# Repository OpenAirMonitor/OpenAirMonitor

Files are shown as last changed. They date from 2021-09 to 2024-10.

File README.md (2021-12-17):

# OpenAirMonitor

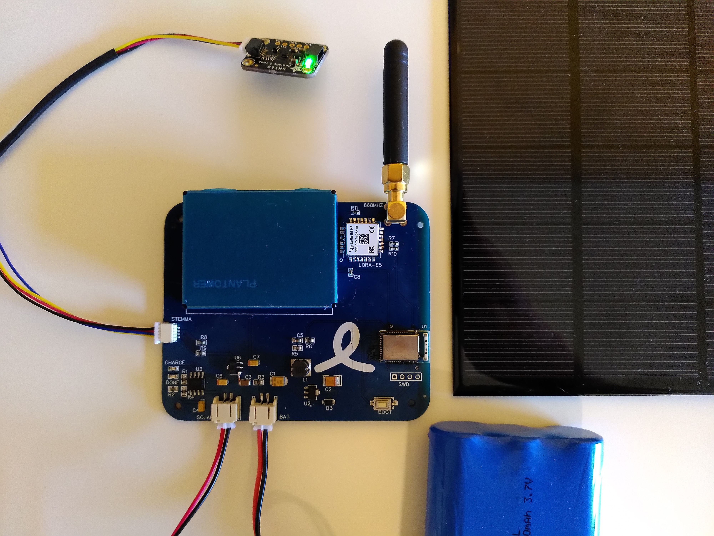
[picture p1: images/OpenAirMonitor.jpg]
OpenAirMonitor


**Work in progress**

The OpenAirMonitor is a solar-powered, outdoor air quality monitor that transmits data over LoRaWAN and Bluetooth LE. It measures particulates (PM1, PM2.5 and PM10), humidity and temperature. The monitor has a STEMMA QT connector, so can be extended with other sensors.

The monitor is programmed in JavaScript over Bluetooth LE using [Espruino](https://www.espruino.com/).

The following components can be connected to the PCB:

- PMS7003 particulate matter sensor
- 868MHz (EU/UK) SMA antenna
- 3.7V LiPo battery, e.g. [this 6600mAh battery](https://shop.pimoroni.com/products/lithium-ion-battery-pack?variant=23417820487)
- 6V solar panel
- [SHT40 temperature & humidity sensor](https://shop.pimoroni.com/products/adafruit-sensirion-sht40-temperature-humidity-sensor-stemma-qt-qwiic) using STEMMA QT connector

## Hardware

See this [OSHWLab project](https://oshwlab.com/gendor/air-quality-monitor) for schematic, PCB layout and Bill of Materials.

The LoRa-E5 module can be obtained from [Seeed Studio's webshop](https://www.seeedstudio.com/LoRa-E5-Wireless-Module-p-4745.html), or as part of their [Fusion PCB Assembly Service](https://www.seeedstudio.com/prototype-pcb-assembly.html).

## Software

Upload `main.js` to the MDBT42Q module over Bluetooth LE using Espruino.

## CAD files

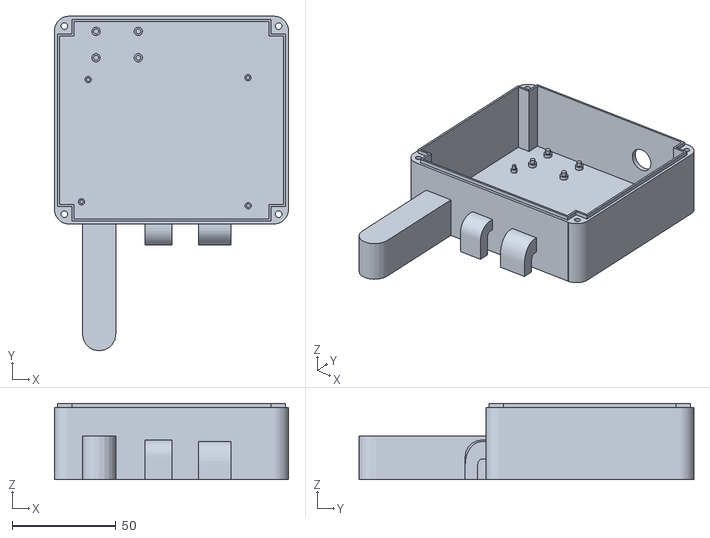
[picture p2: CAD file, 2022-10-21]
enclosure/box_only.stl
112.6 x 161.0 x 36.7

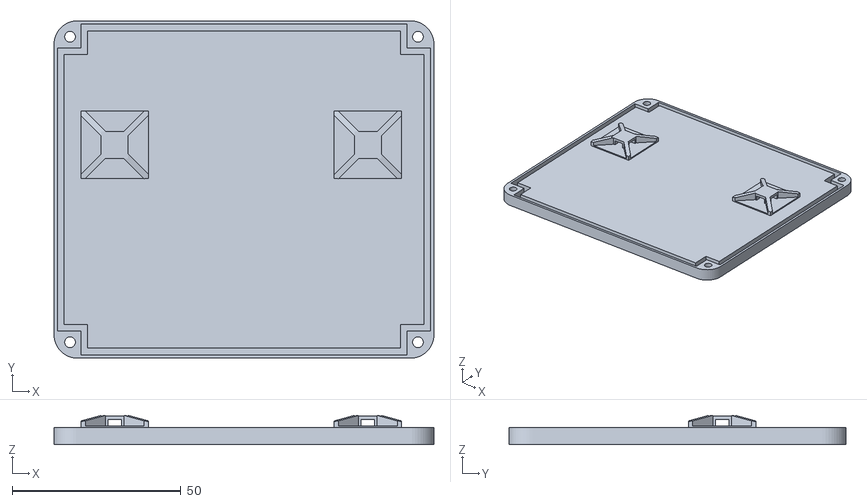
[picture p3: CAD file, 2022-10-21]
enclosure/lid.stl
112.6 x 100.0 x 8.66

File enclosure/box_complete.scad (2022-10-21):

/*
Original version licensed under [CC-BY-SA](https://creativecommons.org/licenses/by-sa/3.0/)
by [mcseven on Thingiverse](https://www.thingiverse.com/thing:1680291)
https://www.thingiverse.com/thing:1680291

Modified by [Gerrit Niezen](https://github.com/OpenAirMonitor/OpenAirMonitor/tree/main/enclosure)

Also contains bent pipe segments from:
https://github.com/fo-am/sonic-kayaks/blob/master/hardware/3dp/pm-box-home-print.scad
Sonic Kayak sensors, electronics designs and waterproofing systems Copyright (C) 2020 FoAM Kernow
CERN Open Hardware Licence Version 2 - Strongly Reciprocal

*/

lid = true;
box = true;

use <include/zip_tie_cable_holder.scad>;

/* [Box Options] */
// Dimension: Box outer X-Size [mm]
box_Size_X          = 112.6;
// Dimension: Box outer Y-Size [mm]
box_Size_Y          = 100;
// Dimension: Box Inner height [mm]
box_Inner_Height    = 33.6;
// Box bottom/top thickness
box_BottomTop_Thickness =  1.2; // [0.6:0.2:3]
// Edge corner radius 
box_Screw_Corner_Radius   =  7; // [2:1:10]
// four outer screw hole diameters
box_Screw_Diameter     =  3.2; // [2:0.2:4]
// Box wall thickness
box_Wall_Thickness     =  2.5; // [0.4:0.2:3.2]
/* [Top Barrier Options] */
// Box barrier thickness
barrier_Thickness  =  1; // [0.4:0.2:3.2]
// Box barrier height
barrier_Height     =  3.8;   // [1.0:0.2:8]
// Additional width on the lid to correct for badly calibrated printers
barrier_Tolerance  =  0.5; // [0.0:0.1:1]
/* [Mouting Screw Nose Options] */
// Number of screw noses
screwnose_Number        = 2; // [0:No noses, 2: one top/one bottom, 4: two top/two bottom]
// Diameter of the noses' screw holes
screwnose_Diameter      = 4; // [2:0.2:8]
// Height of the noses
screwnose_Height        = 5; // [2:0.2:10]
// Wall thickness
screwnose_Wall_Thickness = 2.8; // [2:0.2:5]

$fn = 40;
sideLength = 100;
faceplateLength = 120;
height = 20;
holeLength = 12;

%rotate([0, 0, 180])
translate([-1130, 774, 2])
resize([88, 0, 0], true)
import("include/PCB.stl");

// **************************
// ** Calculated globals
// **************************
boxHeight = box_Inner_Height+box_BottomTop_Thickness;

module box() {
	barrier_Thickness = box_Wall_Thickness-barrier_Thickness;
	difference() {
		union() {
			// solid round box, corners
			translate([box_Screw_Corner_Radius, box_Screw_Corner_Radius, 0]) cylinder(r=box_Screw_Corner_Radius, h=boxHeight, $fn=50); // bottom left
			translate([box_Size_X-box_Screw_Corner_Radius, box_Screw_Corner_Radius, 0]) cylinder(r=box_Screw_Corner_Radius, h=boxHeight, $fn=50); // bottom right
			translate([box_Screw_Corner_Radius, box_Size_Y-box_Screw_Corner_Radius, 0]) cylinder(r=box_Screw_Corner_Radius, h=boxHeight, $fn=50); // top left
			translate([box_Size_X-box_Screw_Corner_Radius, box_Size_Y-box_Screw_Corner_Radius, 0]) cylinder(r=box_Screw_Corner_Radius, h=boxHeight, $fn=50); // bottom right
			// solid round box, inner filling
			translate([0, box_Screw_Corner_Radius, 0]) cube([box_Size_X, box_Size_Y-2*box_Screw_Corner_Radius, boxHeight]);
			translate([box_Screw_Corner_Radius, 0, 0]) cube([box_Size_X-2*box_Screw_Corner_Radius, box_Size_Y, boxHeight]);
			// solid round box, top border
			translate([barrier_Thickness, box_Screw_Corner_Radius+barrier_Thickness, 0]) cube([box_Size_X-2*barrier_Thickness, box_Size_Y-2*box_Screw_Corner_Radius-2*barrier_Thickness, boxHeight+(barrier_Height/2)]);
			translate([box_Screw_Corner_Radius+barrier_Thickness, barrier_Thickness, 0]) cube([box_Size_X-2*box_Screw_Corner_Radius-2*barrier_Thickness, box_Size_Y-2*barrier_Thickness, boxHeight+(barrier_Height/2)]);
      
      // antenna cover
      translate([21.5, -53, 0]) cylinder(r=8, h=21, $fn=20);   
      rotate([90, 0, 0]) translate([13.5, 0, 0]) cube([16, 21, 53]);
		}
		// inner cut-out
		translate([box_Wall_Thickness, box_Screw_Corner_Radius+box_Wall_Thickness, box_BottomTop_Thickness]) cube([box_Size_X-2*box_Wall_Thickness, box_Size_Y-2*box_Screw_Corner_Radius-2*box_Wall_Thickness, boxHeight+barrier_Height]);
		translate([box_Screw_Corner_Radius+box_Wall_Thickness, box_Wall_Thickness, box_BottomTop_Thickness]) cube([box_Size_X-2*box_Screw_Corner_Radius-2*box_Wall_Thickness, box_Size_Y-2*box_Wall_Thickness, boxHeight+barrier_Height]);
		// Screw holes
		translate([(box_Screw_Corner_Radius+box_Wall_Thickness)/2,(box_Screw_Corner_Radius+box_Wall_Thickness)/2,0]) cylinder(r=box_Screw_Diameter/2, h=boxHeight+1, $fn=20);
		translate([(box_Screw_Corner_Radius+box_Wall_Thickness)/2,box_Size_Y-(box_Screw_Corner_Radius+box_Wall_Thickness)/2,0]) cylinder(r=box_Screw_Diameter/2, h=boxHeight+1, $fn=20);
		translate([box_Size_X-(box_Screw_Corner_Radius+box_Wall_Thickness)/2,(box_Screw_Corner_Radius+box_Wall_Thickness)/2,0]) cylinder(r=box_Screw_Diameter/2, h=boxHeight+1, $fn=20);
		translate([box_Size_X-(box_Screw_Corner_Radius+box_Wall_Thickness)/2,box_Size_Y-(box_Screw_Corner_Radius+box_Wall_Thickness)/2,0]) cylinder(r=box_Screw_Diameter/2, h=boxHeight+1, $fn=20);
		// **************************
		// ** YOUR OWN CUTOUTS HERE!
		// **************************
        
        // faceplate
        rotate([90, 0, 0]) {

            translate([7, 0, 0]) {
                
                //antenna hole
                translate([8.5, 1.2, -4])
                   cube([12, 18, 59]);

                
                // PMS7003 holes
                translate([38, 14.5, -(holeLength/2)]) {
                    cube([10, 3, holeLength]);
                    
                    translate([26, -3, 0])
                        cube([12.5, 6, holeLength]);
                }
                
                // hole for solar panel
                translate([70, 17, -(holeLength/2)-sideLength])
                    cylinder(holeLength, d = 12);
                
                // inset for PMS7003 sensor
                // translate([34, 1, -3])
                //     cube([55, 20, 2]);
                
            }
        }

		// **************************
		// ** / CUTOUTS
		// **************************
	}
    /*
	// Lower nose(s)
	if (screwnose_Number==2) translate([box_Size_X/2, 0.001, 0]) mirror([0,1,0]) screwNose(screwnose_Diameter, screwnose_Height);
	if (screwnose_Number==4) {
		translate([box_Size_X*0.25, 0.001, 0]) mirror([0,1,0]) screwNose(screwnose_Diameter, screwnose_Height);
		translate([box_Size_X*0.75, 0.001, 0]) mirror([0,1,0]) screwNose(screwnose_Diameter, screwnose_Height);
	}
	// Upper nose(s)
	if (screwnose_Number==2) translate([box_Size_X/2, box_Size_Y-0.001, 0]) screwNose(screwnose_Diameter, screwnose_Height);
	if (screwnose_Number==4) {
		translate([box_Size_X*0.25, box_Size_Y-0.001, 0]) screwNose(screwnose_Diameter, screwnose_Height);
		translate([box_Size_X*0.75, box_Size_Y-0.001, 0]) screwNose(screwnose_Diameter, screwnose_Height);
	}
    */
}

module mountPCB() {
    translate([1, 1, 0]) {
        translate([12, 9.7, 0]) {
            cylinder(5, d = 1.7);
            cylinder(3, d = 3);
        }

        translate([92.2, 7.8, 0]) {
            cylinder(5, d = 1.7);
            cylinder(3, d = 3);
        }

        translate([92.1, 69.4, 0]) {
            cylinder(5, d = 1.7);
            cylinder(3, d = 3);
        }

        translate([15.2, 68.5, 0]) {
            cylinder(5, d = 1.7);
            cylinder(3, d = 3);
        }
    }
}

module mountSensor() {
    holeDiameter = 2.4;
    holeX = 20.32;
    holeY = 12.7;
    
    translate([20, 80, 0]) {

        cylinder(5, d = holeDiameter);
        cylinder(3, d = 4);


        translate([holeX, 0, 0]) {
            cylinder(5, d = holeDiameter);
            cylinder(3, d = 4);
        }

        translate([0, holeY, 0]) {
            cylinder(5, d = holeDiameter);
            cylinder(3, d = 4);
        }

        translate([holeX, holeY, 0]) {
            cylinder(5, d = holeDiameter);
            cylinder(3, d = 4);
        }
    }
}

module nutHole() {
    cylinder(r=box_Screw_Diameter/2, h=boxHeight, $fn=20);
    cylinder(d=6.2, h=2.6, $fn=6);
}
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

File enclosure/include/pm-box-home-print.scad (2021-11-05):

/*
Downloaded from:
https://github.com/fo-am/sonic-kayaks/blob/master/hardware/3dp/pm-box-home-print.scad

Sonic Kayak sensors, electronics designs and waterproofing systems Copyright (C) 2020 FoAM Kernow

CERN Open Hardware Licence Version 2 - Strongly Reciprocal

*/

$fs=0.5; 
$fa=0.5; 

module sensor() {
    color("blue") 
    cube([47.7,36.7,11.7]);

    // plug
    color("black")
    translate([1.85,36.7-10-2.85,12])
    square([6,10]);

    // air out
    color("black")
    translate([4.45,37,11.7-2-8.75])
    rotate([90,0,0])
    square([9.8,2]);

    // air in
    color("black")
    translate([0,37,11.7-4.4-6.45])
    translate([47.7-11-4.45,0,0]) // ???
    rotate([90,0,0])
    square([11,4.4]);
}

nipple_width=13.0;
nipple_hole_width=11.0;
nipple_height=18.0;
nipple_hole_height=4.0;

module bent_pipe() {
    rotate([0,90,90]) {
        rotate_extrude(angle=90) {
            translate([5,0,0])
            difference() {
                square([6,nipple_width],true);
                square([4,nipple_hole_width],true);
            }            
        }
        translate([5,-1.5,0])
        difference() {
            cube([6,3,nipple_width],true);
            cube([4,3.1,nipple_hole_width],true);
        }
    }
}

module nipple() {
    bent_pipe();
}



module nipples() {
    // in nipple
    translate([69.2,40+2,0])
    rotate([90,90,0])
    nipple();

    // out nipple
    translate([41,40+2,0])
    rotate([90,90,0])
    nipple();
}


//translate([31.5,1.5,4.5]) sensor();

// internal space
//translate([0,0,0])
//color([1,1,1,0.5])
//cube([80,40,20]);

// 6-10mm internal pipe diameter


translate([0,0,3])
difference() {
    union() {
        // bottom wall
        translate([-3,-3,-3]) cube([86,46,3]);
        // back wall
        translate([0,-3,0]) cube([80,3,22]);
        // back wall
        translate([0,40,0]) cube([80,3,22]);
        // end wall
        translate([-3,-3,0]) cube([3,46,22]);
        // end wall
        translate([80,-3,0]) cube([3,46,22]);

        nipples();
        // bottom spacer
        translate([30,-3,-0.5]) cube([50,46,2]);
        // air separators
        translate([30,38.5,0])
        union() {
            cube([2,2,15]);
            translate([0,0,13])
            cube([50.5,2,2]);
            translate([20,0,0])
            cube([10,2,15]);
        }
    }
        
    translate([33,42.5,5])
    rotate([-90,180,0])
    linear_extrude(height=3) {
        union() {
            scale([0.3,0.3,1]) {
//                text("Sonic Kayaks");
                text("Sonic Bikes");
                translate([0,-13,0])
                text("Air pollution sensor");
            }
//            translate([0,5,0])
//            scale([0.75,0.75,1])
//            import("foam-logo-seg.dxf");
            scale([0.5,0.5,0.5])
            translate([0,-252,0])
            import("bri-logo.dxf");
        }
    }
    
    // cut holes through box and nipples 
    union() {
        translate([69.2,40.01,4])
        rotate([90,0,0])
        union () {
            cube([nipple_hole_width,4,10], true);
            translate([41-69.2,0,0])
            cube([nipple_hole_width,4,10], true);
        }
        translate([-5,30,15])
        rotate([0,90,0])
        cylinder(d=3.5,h=10);
    }
}


// lid
translate([-3,-5,3]) 
rotate([180,0,0])
union() {
    cube([86,46,3]);
    translate([3.5,3.5,-2])
    cube([79,39,2]);
}

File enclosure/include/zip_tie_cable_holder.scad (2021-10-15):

/*

Zip Tie Anchor by
[PeterEllens](https://www.thingiverse.com/thing:24187)
is licensed under a [CC-BY license](https://creativecommons.org/licenses/by/4.0/)

Modified by [Gerrit Niezen](https://github.com/OpenAirMonitor/OpenAirMonitor/tree/main/enclosure)

*/

module zip_tie_anchor() {
    base_width = 20;
    base_height = 1;
    gap_width = 4;
    gap_height =2;
    top_width = 8;
    top_height = 2.3;
    cross_width = 1.8;

    diaginal_width = sqrt(base_width*base_width+base_width*base_width);

    difference () {
    union() {
    cube(size=[base_width,base_width,base_height],center=true);
    translate(v=[0,0,base_height+(gap_height-base_height)/2]) cube(size=[top_width,top_width,top_height+gap_height],center=true);

    rotate(a=[0,11,45]) translate(v=[diaginal_width/4,0,base_height+gap_height]) cube(size=[diaginal_width/2,cross_width,gap_height+1],center=true);

    rotate(a=[0,11,90+45]) translate(v=[diaginal_width/4,0,base_height+gap_height]) cube(size=[diaginal_width/2,cross_width,gap_height+1],center=true);

    rotate(a=[0,11,180+45]) translate(v=[diaginal_width/4,0,base_height+gap_height]) cube(size=[diaginal_width/2,cross_width,gap_height+1],center=true);

    rotate(a=[0,11,270+45]) translate(v=[diaginal_width/4,0,base_height+gap_height]) cube(size=[diaginal_width/2,cross_width,gap_height+1],center=true);


    }
    translate(v=[0,0,base_height+(gap_height-base_height)/2]) cube(size=[gap_width,top_width+1,gap_height],center=true);
    translate(v=[0,0,base_height+(gap_height-base_height)/2]) cube(size=[top_width+1,gap_width,gap_height],center=true);

    translate(v=[0,0,base_height+(gap_height+base_height)]) cube(size=[top_width,top_width,top_height-gap_height+0.6],center=true);

    translate(v=[0,0,-base_height-(base_height)/2]) cube(size=[base_width+2,base_width+2,base_height*2],center=true);

    translate(v=[0,base_width,0]) cube(size=[base_width+5,base_width,base_height+gap_height+1],center=true);

    translate(v=[0,-base_width,0]) cube(size=[base_width+5,base_width,base_height+gap_height+1],center=true);

    translate(v=[base_width,0,0]) cube(size=[base_width,base_width+5,base_height+gap_height+1],center=true);

    translate(v=[-base_width,0,0]) cube(size=[base_width,base_width+5,base_height+gap_height+1],center=true);

    }
}

zip_tie_anchor();

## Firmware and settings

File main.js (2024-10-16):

const PMS = require('PMS7003');

const lora = {
  pins: {
    tx: D8,
    rx: D6
  },
  resetPin: D3,
};

let pmsData = null;
var pms = null;
let shtData = null;
let batteryVoltage = null;
let batteryPercentage = null;
let batteryChargeRate = null;
let joined = false;

const SCL_SDA = {
  "scl": D14,
  "sda": D13
};
const ENABLE_PM = D12;
const PM_DATA = D5;
const ENABLE_5V = D19;
const PM_INTERVAL = 3600000; // 60 minutes
const READ_TIME = 30000;
const RETRY_JOIN_DELAY = 20000;
const HAS_FUEL_GAUGE = false; // can use MAX1704X fuel gauge
const USE_SHT31 = false; // can use SHT31 instead of SHT40

const onPms = (d) => {
  // TODO: consider averaging the values
  if (d.checksumOk) {
    console.log('PM 2.5 data: ', d.dAtm.pm2_5);
    pmsData = d;
  } else {
    console.log('PMS checksum error!');
  }
  sht.read(function(d) {
    console.log('Temperature:', d.temp);
    console.log('Humidity:', d.humidity);
    shtData = d;
  });

  if (HAS_FUEL_GAUGE) {
    batteryPercentage = fuelGauge.readPercent();
    console.log(`Battery percent: ${batteryPercentage} %`);

    batteryVoltage = fuelGauge.readVoltage();
    console.log(`Battery voltage: ${batteryVoltage} V`);

    batteryChargeRate = fuelGauge.readChargeRate();
    console.log(`Battery charge rate: ${batteryChargeRate} %/hr`);

    pinVoltage = (analogRead(D31) * 3.3) * (100 + 30) / 100;
    console.log('Voltage read from pin:', pinVoltage);
  } else {
    batteryVoltage = (analogRead(D31) * 3.3) * (100 + 30) / 100;
    console.log('Voltage read from pin:', batteryVoltage);
  }
};

const arrayBufferToHex = (arrayBuffer) => {
  return (new Uint8Array(arrayBuffer)).slice().map(x => (256 + x).toString(16).substr(-2)).join("");
};

const loraSetup = (init = false) => {
  let buf = '';
  Serial1.setup(9600, lora.pins);
  digitalWrite(lora.resetPin, 1); // keep LoRa reset pin high
  if (init) {
    lora.on('MSGHEX', (result) => {
      if (result.type === 'Done') {
        lora.emit('done');
      }
    });
    lora.on('JOIN', (result) => {
      if (result.type === 'Join failed') {
        console.log('Could not join the network');
        lora.emit('retry');
      }
      if (result.type === 'Network joined') {
        console.log('Successfully joined the network');
        joined = true;
        lora.emit('ready');
      }
    });
    lora.on('MODE', (result) => {
      if (result.type === 'LWOTAA') {
        console.log('Set mode to OTAA');
        Serial1.println('AT+JOIN');
      } else {
        console.log('Could not configure channels');
      }
    });
    lora.on('CH', (result) => {
      if (result.type === 'NUM' && result.value === '0-2') {
        console.log('Configured channels');
        Serial1.println('AT+MODE=LWOTAA');
      } else {
        console.log('Could not configure channels');
      }
    });
    lora.on('DR', (result) => {
      if (result.type === 'EU868') {
        console.log('Data rate set to 868MHz');
        Serial1.println('AT+CH=NUM,0-2');
      } else {
        console.log('Could not set data rate');
      }
    });
    Serial1.println('AT+DR=EU868');
  }
  // this should be after the other lora event listeners
  Serial1.on('data', (data) => {
    buf += data;
    var idx = buf.indexOf("\r");
    while (idx >= 0) {
      const line = buf.substr(0, idx);
      buf = buf.substr(idx + 1);
      // print(line);
      const res = /\+(\w+):\s+([\w\s]+),*\s*(.*)/.exec(line);
      if (res) {
        const result = {
          cmd: res[1],
          type: res[2],
          value: res[3],
        };
        lora.emit(result.cmd, result);
      }
      idx = buf.indexOf("\r");
    }
  });
};

const Ranges = {
  DIGITAL_INPUT: [0, 255],
  DIGITAL_OUTPUT: [0, 255],
  ANALOG_INPUT: [-327.68, 327.67],
  ANALOG_OUTPUT: [-327.68, 327.67],
  LUMINOSITY: [0, 65535],
  PRESENCE: [0, 1],
  TEMPERATURE: [-3276.8, 3276.7],
  RELATIVE_HUMIDITY: [0, 100],
  ACCELEROMETER: [-32.768, 32.767],
  MAGNETOMETER: [-32.768, 32.767],
  BAROMETRIC_PRESSURE: [0, 6553.5],
  GYROMETER: [-327.68, 327.67],
  GPS_LATITUDE: [-90.0, 90.0],
  GPS_LONGITUDE: [-180.0, 180.0],
  GPS_ALTITUDE: [-3276.8, 3276.7],
};

const Scales = {
  DIGITAL_INPUT: 1,
  DIGITAL_OUTPUT: 1,
  ANALOG_INPUT: 100,
  ANALOG_OUTPUT: 100,
  LUMINOSITY: 1,
  PRESENCE: 1,
  TEMPERATURE: 10,
  RELATIVE_HUMIDITY: 2,
  ACCELEROMETER: 1000,
  MAGNETOMETER: 1000,
  BAROMETRIC_PRESSURE: 10,
  GYROMETER: 100,
  GPS_LATITUDE: 10000,
  GPS_LONGITUDE: 10000,
  GPS_ALTITUDE: 100,
};

const Sizes = {
  DIGITAL_INPUT: 1,
  DIGITAL_OUTPUT: 1,
  ANALOG_INPUT: 2,
  ANALOG_OUTPUT: 2,
  LUMINOSITY: 2,
  PRESENCE: 1,
  TEMPERATURE: 2,
  RELATIVE_HUMIDITY: 1,
  ACCELEROMETER: 6,
  MAGNETOMETER: 6,
  BAROMETRIC_PRESSURE: 2,
  GYROMETER: 6,
  GPS: 9,
  CHANNEL_TYPE: 2,
  UINT8: 1,
  UINT16: 2,
  INT16: 2,
  THREE_AXIS: 6,
};

const Types = {
  DIGITAL_INPUT: 0,
  DIGITAL_OUTPUT: 1,
  ANALOG_INPUT: 2,
  ANALOG_OUTPUT: 3,
  LUMINOSITY: 101,
  PRESENCE: 102,
  TEMPERATURE: 103,
  RELATIVE_HUMIDITY: 104,
  ACCELEROMETER: 113,
  MAGNETOMETER: 114,
  BAROMETRIC_PRESSURE: 115,
  GYROMETER: 134,
  GPS: 136,
};

const rangeCheck = (min, max, value) => {
  if (value < min || value > max) {
    throw new RangeError(`The argument must be between ${min} and ${max}.`);
  }
};

const encodeChannelType = (channel, type) => {
  const buffer = new ArrayBuffer(Sizes.CHANNEL_TYPE);
  const dataView = new DataView(buffer);
  let offset = 0;
  [channel, type].forEach((value) => {
    dataView.setInt8(offset, value);
    offset += 1;
  });
  return buffer;
};

const encodeInt16 = function encodeInt16(value, scale) {
  if (scale == null) {
    scale = 1;
  }
  const buffer = new ArrayBuffer(Sizes.INT16);
  const dataView = new DataView(buffer);
  dataView.setInt16(0, (value * scale) | 0);
  return buffer;
};

const encodeUInt8 = function encodeUInt8(value, scale) {
  if (scale == null) {
    scale = 1;
  }
  const buffer = new ArrayBuffer(Sizes.UINT8);
  const dataView = new DataView(buffer);
  dataView.setUint8(0, (value * scale) | 0);
  return buffer;
};

var concatBuffer = (buffer1, buffer2) => {
  var tmp = new Uint8Array(buffer1.byteLength + buffer2.byteLength);
  tmp.set(new Uint8Array(buffer1), 0);
  tmp.set(new Uint8Array(buffer2), buffer1.byteLength);
  return tmp.buffer;
};

const encodeAnalogInput = (channel, value) => {
  const min = Ranges.ANALOG_INPUT[0];
  const max = Ranges.ANALOG_INPUT[1];
  rangeCheck(min, max, value);
  const chanb = encodeChannelType(channel, Types.ANALOG_INPUT);
  const snsb = encodeInt16(value, Scales.ANALOG_INPUT);
  return concatBuffer(chanb, snsb);
};

const encodeTemperature = (channel, degc) => {
  const min = Ranges.TEMPERATURE[0];
  const max = Ranges.TEMPERATURE[1];
  rangeCheck(min, max, degc);
  const chanb = encodeChannelType(channel, Types.TEMPERATURE);
  const snsb = encodeInt16(degc, Scales.TEMPERATURE);
  return concatBuffer(chanb, snsb);
};

const encodeHumidity = (channel, percent) => {
  const min = Ranges.RELATIVE_HUMIDITY[0];
  const max = Ranges.RELATIVE_HUMIDITY[1];
  rangeCheck(min, max, percent);
  const chanb = encodeChannelType(channel, Types.RELATIVE_HUMIDITY);
  const snsb = encodeUInt8(percent, Scales.RELATIVE_HUMIDITY);
  return concatBuffer(chanb, snsb);
};

function MAX1704X(_i2c) {
  this.i2c = _i2c;
  this.reset();
}

MAX1704X.prototype.reset = function() {
  try {
    this.i2c.writeTo(0x36, [0xFE, 0x54, 0x00]);
  } catch (err) {
    if (err.message.includes('33282')) {
      // we got a NACK, which is what we want
      return;
    } else {
      throw new Error('Something went wrong during reset()');
    }
  }
};

MAX1704X.prototype.readRegister = function(register) {
  this.i2c.writeTo({
    address: 0x36,
    stop: false
  }, [register]);
  return new DataView(this.i2c.readFrom(0x36, 3).buffer);
};


MAX1704X.prototype.readICVersion = function() {
  return this.readRegister(0x08).getUint16().toString(16);
};

MAX1704X.prototype.readPercent = function() {
  return this.readRegister(0x04).getUint16() / 256.0;
};

MAX1704X.prototype.readVoltage = function(callback) {
  return this.readRegister(0x02).getUint16() * 78.125 / 1000000;
};

MAX1704X.prototype.readChargeRate = function(callback) {
  return this.readRegister(0x16).getInt16() * 0.208;
};

var connect2 = function(_i2c) {
  return new MAX1704X(_i2c);
};

lora.on('ready', () => {
  console.log('Finished setup, putting LoRa modem to sleep');
  Serial1.println('AT+LOWPOWER');
  lora.on('data', (pmsData, shtData, batteryVoltage) => {
    console.log('Disconnecting PM..');
    Serial1.unsetup();
    loraSetup();
    if (pmsData) {
      const pm10 = encodeAnalogInput(1, pmsData.dAtm.pm10);
      const pm2_5 = encodeAnalogInput(2, pmsData.dAtm.pm2_5);
      const temp = encodeTemperature(3, shtData.temp);
      const humidity = encodeHumidity(4, Math.round(shtData.humidity));
      const battery = encodeAnalogInput(5, batteryVoltage);
      const chargeRate = encodeAnalogInput(6, batteryChargeRate);
      // works with https://revspace.nl/Sensor-data-bridge
      const toSend = arrayBufferToHex(pm10) +
        arrayBufferToHex(pm2_5) +
        arrayBufferToHex(temp) +
        arrayBufferToHex(humidity);
      // The following can't be uploaded to sensor.community
      // arrayBufferToHex(battery) +
      // arrayBufferToHex(chargeRate);
      pmsData = null;
      Serial1.println('A'); // wakeup LoRa modem
      setTimeout(() => {
        Serial1.println(`AT+MSGHEX="${toSend}"`);
        console.log(`Sending ${toSend}`);
      }, 5);
    } else {
      console.log('No PM data available.');
    }
  });
});

lora.on('done', () => {
  console.log('Sent message, putting LoRa modem to sleep');
  Serial1.println('AT+LOWPOWER');
});

lora.on('retry', () => {
  console.log(`Waiting ${RETRY_JOIN_DELAY/1000} seconds before trying to join network again..`);
  setTimeout(() => {
    console.log('Attempting to join..');
    Serial1.println('AT+JOIN');
  }, RETRY_JOIN_DELAY);
});

function SHT31(_i2c) {
  this.i2c = _i2c;
}

// read with callback({humidity,temp})
SHT31.prototype.read = function(callback) {
  // high repeatability with clock stretching disabled
  this.i2c.writeTo(0x44, [0x24, 0x00]);
  var sht = this;
  setTimeout(function() {
    var d = new DataView(sht.i2c.readFrom(0x44, 6).buffer);
    callback({
      temp: d.getUint16(0) * 175 / 65536 - 45,
      humidity: d.getUint16(3) * 125 / 65536 - 6
    });
  }, 20);
};

var connect3 = function(_i2c) {
  return new SHT31(_i2c);
};

I2C1.setup(SCL_SDA);

var sht = null;
if (USE_SHT31) {
  sht = connect3(I2C1);
} else {
  sht = require('SHT4x').connect(I2C1);
}

var fuelGauge = null;
if (HAS_FUEL_GAUGE) {
  fuelGauge = connect2(I2C1);
}

digitalWrite(ENABLE_PM, 0);
digitalWrite(ENABLE_5V, 0);
Bluetooth.setConsole(true);

setTimeout(() => {
  loraSetup(true);
}, 1000); // Give LoRa-E5 time to start up

const pmInterval = setInterval(() => {
  if (joined) {
    console.log('Turning on PM..');
    Serial1.unsetup();
    Serial1.removeAllListeners('data');
    digitalWrite(ENABLE_5V, 1);
    pms = PMS.connect(Serial1, PM_DATA, ENABLE_PM, onPms);
    pms.wakeup();
    const readTime = setTimeout(() => {
      console.log('Turning off PM..');
      pms.sleep();
      digitalWrite(ENABLE_5V, 0);
      setTimeout(() => {
        // wait for PM sensor to sleep before sending data
        lora.emit('data', pmsData, shtData, batteryVoltage);
      }, 1000);
    }, READ_TIME);
  }
}, PM_INTERVAL);

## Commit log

2021-09-14 started on enclosure
    [PCB.dxf, main.scad, test.stl]
2021-09-17 faceplate works; working on full enclosure
    [main.scad, test.stl]
2021-10-01 replace with waterproof enclosure
    [box_complete.scad, box_complete.stl, main.scad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]
2021-10-01 fix PMS7003 holes and box width; add zip tie holder and sensor mounting holes
    [box_complete.scad]
2021-10-01 added nipples; moved hole for solar panel; increased lid thickness for o-ring
    [box_complete.scad, box_complete.stl]
2021-10-01 move sensor mounting holes to bottom; offset zip tie anchors
    [box_complete.scad, box_complete.stl]
2021-10-08 switch serial port when enabling PM sensor
2021-10-08 add external libraries
    [pm-box-home-print.scad, zip_tie_cable_holder.scad]
2021-10-08 add holes for sunk hex nuts
    [box_complete.scad]
2021-10-15 adjust o-ring thickness; nut hole depth; and zip tie thickness
    [box_complete.scad, zip_tie_cable_holder.scad]
2021-10-15 add retry on failed network join
    [main.js]
2021-10-29 switch to CayenneLPP encoding
2021-11-05 lower box height by width of washer; make antenna hole a tiny bit smaller
    [box_complete.scad]
2021-11-05 extend nipples; move antenna hole; cleanup
    [PCB.dxf, box_complete.scad, box_only.stl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]
2021-11-05 selectively print box or lid
    [box_complete.scad]
2021-12-03 resize antenna hole; remove PM sensor inset for rev2 board
    [box_complete.scad]
2021-12-03 change SCL and SDA for rev2 board
2021-12-17 send temperature over LoRaWAN
2022-01-07 also send battery voltage
2022-10-21 enclosure for rev2 and rev3 pcb
    [box_complete.scad, box_complete.stl, box_only.stl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]
2022-12-02 replace LC709203F fuel gauge with MAX17048; add battery charge rate
    [main.js]
2023-01-13 put LoRa modem to sleep; use true shutdown for 5V regulator
2024-10-16 improve formatting; sends to sensor.community
